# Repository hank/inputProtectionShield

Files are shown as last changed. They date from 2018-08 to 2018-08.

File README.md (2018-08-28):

# inputProtectionShield

The [JTAGULATOR](http://www.grandideastudio.com/portfolio/jtagulator/) took an existing project, the [JTAGENUM](https://github.com/cyphunk/JTAGenum), and reinvented the wheel in a few places. JTAGENUM runs on Arduino, and so this shield provides the Arduino Nano with the exact same hardware capabilities as the JTAGULATOR without the [hefty ($170 for a kit) price tag](https://hackerwarehouse.com/product/jtagulator/).

These hardware capabilities include:

* Input level conversion, including a range from 1.8-5v logic (larger range than JTAGulator)
* Input protection with current limiting and Schottky diode array

## Board

| | |
| --- | --- |
|  | Imgur |

## Bill Of Materials

* If the HSMS-285R is unavailable, the following parts should work:
  * [NUP4302MR6](http://www.mouser.com/ds/2/308/NUP4302MR6-99757.pdf)
  * [TESD5V0V4UCU6 RFG](www.taiwansemi.com/products/datasheet/TESD5V0V4UCU6_A1705.pdf) (Bought 12 for $4.13, 4x for $1.37)
* MOSFETs: [50pcs BSS138  MOSFET N-CH 50V .22 AMP IN SOT-23 PKG. USA SUPPLIER](http://www.ebay.com/itm/382540619634) ($3.25, $0.065 each, 8x for $0.52)
* Resistors:
  * [Lot of 125 CRCW04021K00FKTD Vishay Chip Resistor 1k Ohm 62.5mW 1/16W 1% 0402 NOS](http://www.ebay.com/itm/201820263322) ($3.99, $0.03192 each, 16x for $0.51)
  * [Lot of 75 RK73H1ELTP1002F KOA Chip Resistor 10k Ohm 100mW 1/10W 1% 0402 NOS](http://www.ebay.com/itm/201683750387) ($5.40, $0.072 each, 8x for $0.57)
* Arduino: [Arduino Nano V3.0 ATmega328 5V Micro-controller CH340E](http://www.ebay.com/itm/391965564336) ($11.50)
* Boards: 6 for $13.40 from OSHPark, $2.23 each

**Total: $16.70** per unit

| **Part** | **Value** | **Device** | **Package** | **Description** |
| --- | --- | --- | --- | --- |
| D1-D4 (4x) | HSMS-285R | HSMS-285R | SOT363 | Surface Mount Microwave Schottky Detector Diodes Ring Quad |
| Q1-Q8 (8x) | BSS138 | MOSFET-NCHANNELSMD | SOT23-3 | BSS138 MOSFET |
| R1-R15, R17 (16x) | 10k | R-US_R0402 | R0402 | RESISTOR, American symbol |
| R16, R18-R24 (8x) | 1k | R-US_R0402 | R0402 | RESISTOR, American symbol |
| SV1 | | FE15-1 | FE15 | FEMALE HEADER |
| SV2 | | FE15-1 | FE15 | FEMALE HEADER |
| SV3 | | MA03-1 | MA03-1 | PIN HEADER |
| | ARDUINO NANO | ARDUINO NANO | PDIP-32 | Arduino Nano |

## Credits

* [JTAGulator Versus JTAGENUM Blog Post](https://p16.praetorian.com/blog/jtagulator-vs-jtagenum-tools-for-identifying-jtag-pins-in-iot-devices) and original board design by Dylan Ayrey. Great work!
* Board layout tweaks (so far just the silkscreening fonts and other aesthetic tweaks) by Erik Gregg

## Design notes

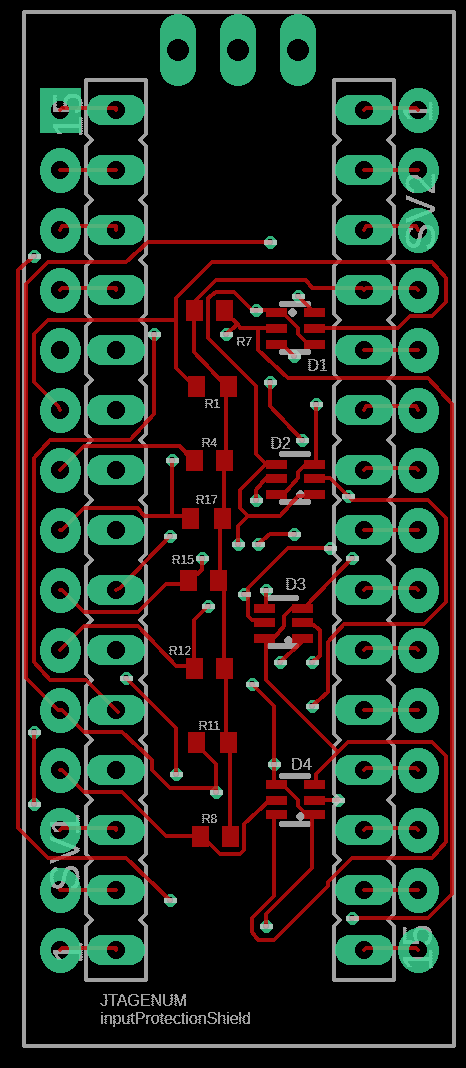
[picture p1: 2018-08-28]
top.png

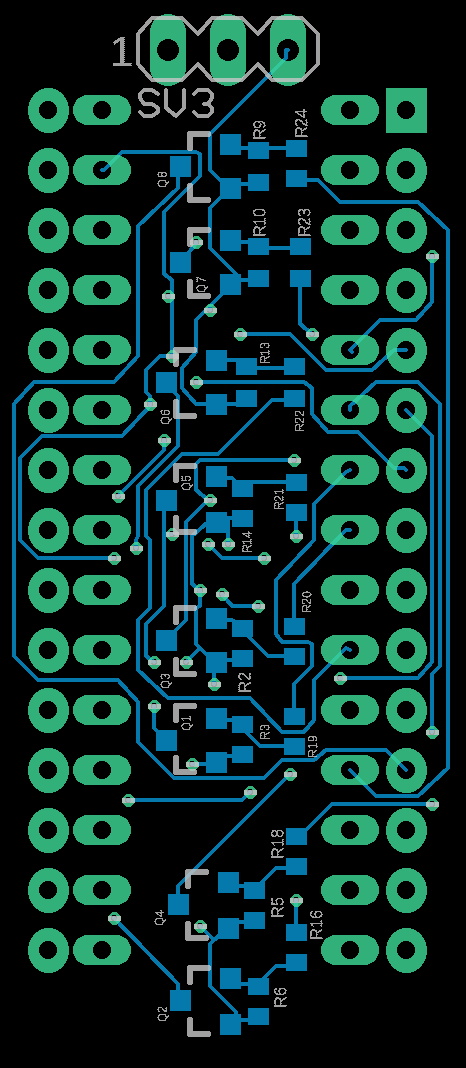
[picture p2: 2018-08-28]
bottom.png

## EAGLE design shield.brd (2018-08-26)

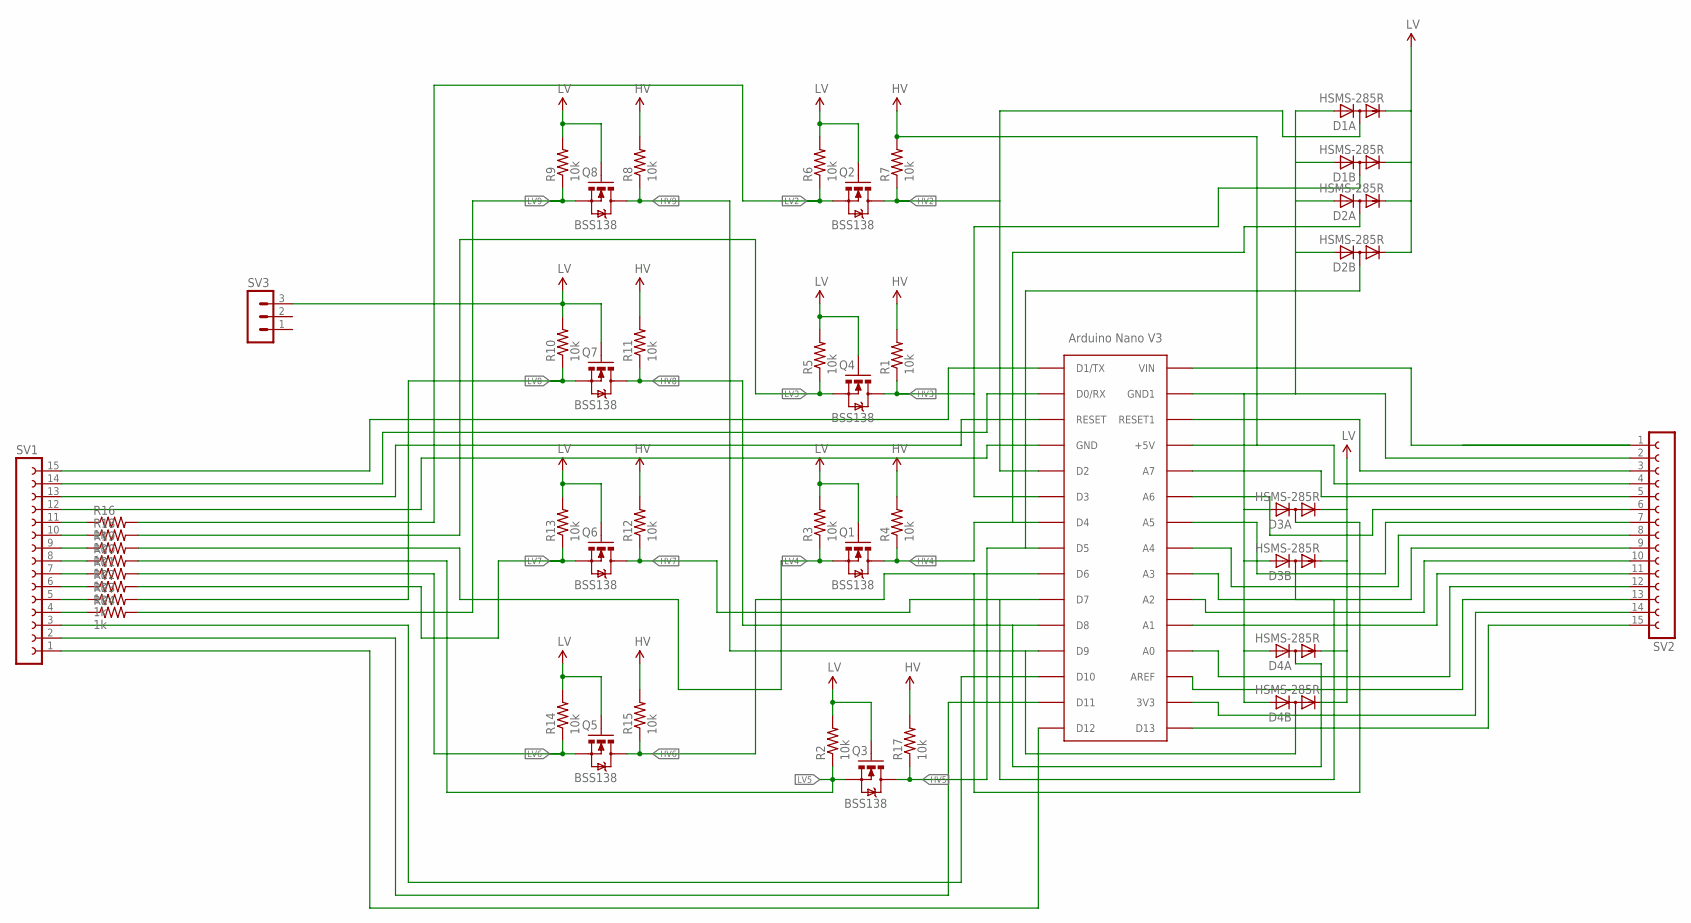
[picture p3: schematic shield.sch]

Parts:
D1, D2, D3, D4: HSMS-285R; SOT363
Q1, Q2, Q3, Q4, Q5, Q6, Q7, Q8: BSS138; SOT23-3
R1, R2, R3, R4, R5, R6, R7, R8, R9, R10, R11, R12, R13, R14, R15, R17: 10k; R0402
R16, R18, R19, R20, R21, R22, R23, R24: 1k; R0402
SV1, SV2: FE15-1; FE15
SV3: MA03-1
U$1: ARDUINONANO; PDIP-32

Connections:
HV: R1.2, R4.2, R7.2, R8.2, R11.2, R12.2, R15.2, R17.2, SV2.4, U$1.+5V
HV2: D1.2 (AC), Q2.3 (D), R7.1, U$1.D2
HV3: D1.5 (AC), Q4.3 (D), R1.1, U$1.D3
HV4: D2.2 (AC), Q1.3 (D), R4.1, U$1.D4
HV5: D2.5 (AC), Q3.3 (D), R17.1, U$1.D5
HV6: D3.2 (AC), Q5.3 (D), R15.1, U$1.D6
HV7: D3.5 (AC), Q6.3 (D), R12.1, U$1.D7
HV8: D4.2 (AC), Q7.3 (D), R11.1, U$1.D8
HV9: D4.5 (AC), Q8.3 (D), R8.1, U$1.D9
LV: D1.1 (C), D1.4 (C), D2.1 (C), D2.4 (C), D3.1 (C), D3.4 (C), D4.1 (C), D4.4 (C), Q1.1 (G), Q2.1 (G), Q3.1 (G), Q4.1 (G), Q5.1 (G), Q6.1 (G), Q7.1 (G), Q8.1 (G), R2.2, R3.2, R5.2, R6.2, R9.2, R10.2, R13.2, R14.2, SV3.3
LV2: Q2.2 (S), R6.1, R16.2
LV3: Q4.2 (S), R5.1, R18.2
LV4: Q1.2 (S), R3.1, R19.2
LV5: Q3.2 (S), R2.1, R20.2
LV6: Q5.2 (S), R14.1, R21.2
LV7: Q6.2 (S), R13.1, R22.2
LV8: Q7.2 (S), R10.1, R23.2
LV9: Q8.2 (S), R9.1, R24.2
unnamed: D1.3 (A), D1.6 (A), D2.3 (A), D2.6 (A), D3.3 (A), D3.6 (A), D4.3 (A), D4.6 (A), SV2.2, U$1.GND1
unnamed: SV2.9, U$1.A4 (A3)
unnamed: SV2.10, U$1.A5 (A2)
unnamed: SV2.11, U$1.A6 (A1)
unnamed: SV2.12, U$1.A7 (A0)
unnamed: SV2.13, U$1.AREF
unnamed: SV2.14, U$1.3V3
unnamed: SV2.15, U$1.D13
unnamed: SV2.8, U$1.A3 (A4)
unnamed: SV2.7, U$1.A2 (A5)
unnamed: SV2.6, U$1.A1 (A6)
unnamed: SV2.5, U$1.A0 (A7)
unnamed: R16.1, SV1.11
unnamed: SV2.3, U$1.RESET1
unnamed: SV2.1, U$1.VIN
unnamed: SV1.15, U$1.D1/TX
unnamed: SV1.14, U$1.D0/RX
unnamed: SV1.13, U$1.RESET
unnamed: SV1.12, U$1.GND
unnamed: R18.1, SV1.10
unnamed: R19.1, SV1.9
unnamed: R20.1, SV1.8
unnamed: R21.1, SV1.7
unnamed: R22.1, SV1.6
unnamed: R23.1, SV1.5
unnamed: R24.1, SV1.4
unnamed: SV1.3, U$1.D10
unnamed: SV1.2, U$1.D11
unnamed: SV1.1, U$1.D12

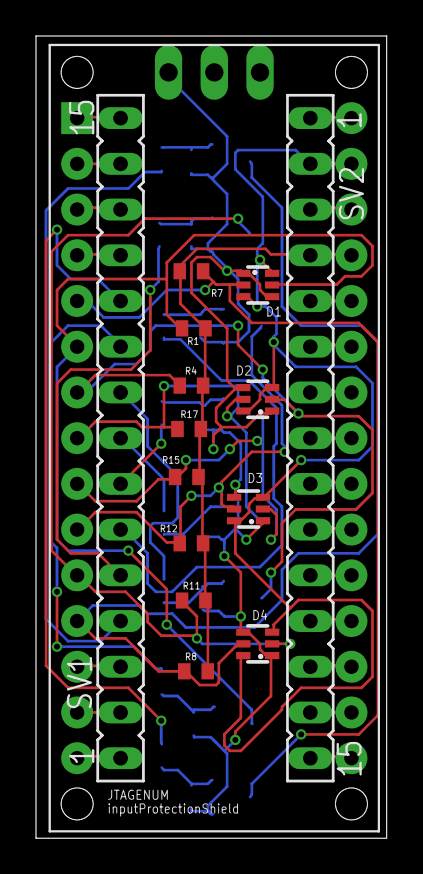
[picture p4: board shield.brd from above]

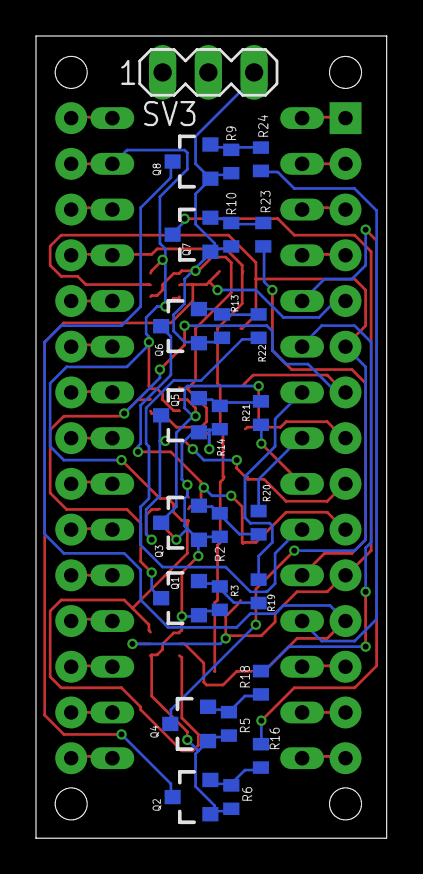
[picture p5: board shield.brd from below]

Board: 2 copper layers, 19.5 x 44.6 mm, 40 parts (25 on the bottom side), 47 nets.

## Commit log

2016-03-06 adding shield schematic and board designs
    [shield.brd, shield.sch]
2016-03-06 fixing ground line
    [shield.brd, shield.sch]
2016-03-06 optimizing board layout using reverse side for mounting
    [shield.brd]
2016-03-07 reducing size dramatically
    [shield.brd]
2018-08-26 Adding silk name
    Adding a silked name of the board so I don't forget what it is.
    [shield.brd]
2018-08-26 More updates, ordered boards
    [shield.brd]
2018-08-28 Updating Docs
    Adding docs with BOM, better pictures, etc.
